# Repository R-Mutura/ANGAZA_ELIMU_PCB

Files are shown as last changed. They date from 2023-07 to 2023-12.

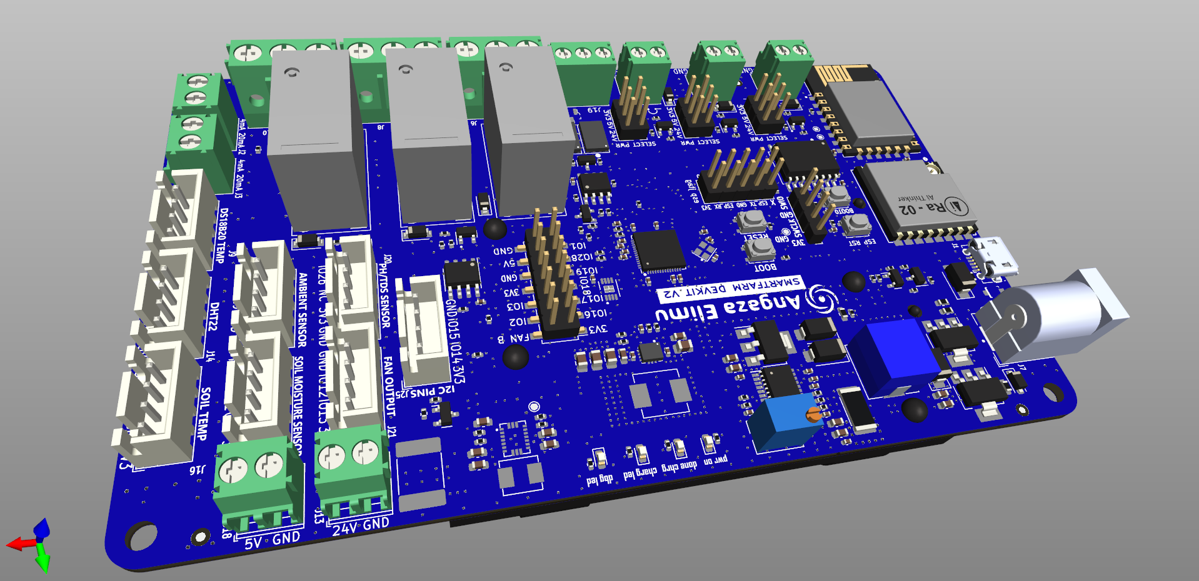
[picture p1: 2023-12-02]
images/RpiPico_Agriboard 4.png

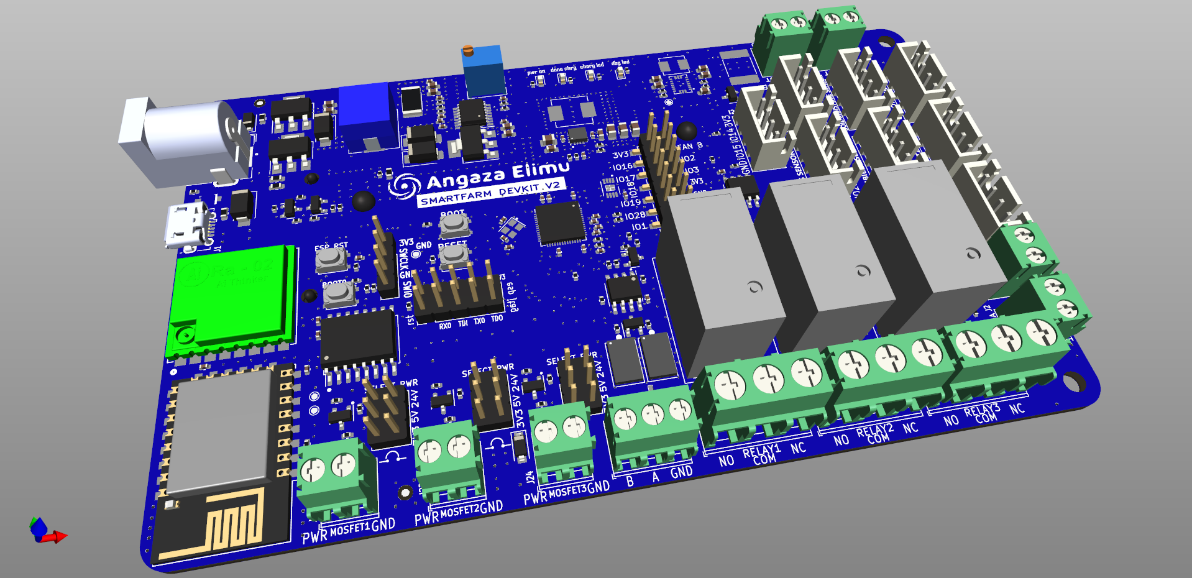
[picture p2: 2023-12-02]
images/RpiPico_Agriboard 3.png

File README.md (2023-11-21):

# ANGAZA_ELIMU_PCB

This repo contains the Hardware design and production files for the `Angaza Elimu Smart Farm` board.
 ###  Version 1.0.0 Solarless_Board 
 please refer to the attached release for all the production files.

## Description
The board main features of this Board include:
- RP2040TR7 - Rpi-Pico as the main MCU
- ESP12F - to prvide BLE and WiFi capabilties
- Lora Module RA-02 - with SMA connector  for extrnal antenna support - frequency 868mHz
- RS485 for communication with ground based sensor.
- Relay isolated outputs
- Mosfet Output with selectable power source - Lowside driver configuration
- 24V and 5V output - with overcurrent protection
- 0mA - 20mA  / 4mA - 20mA sensor input (eg Platinum temeprature sensor)
- and other communication interfaces

POWER FEATURES
- 24V  input
- Battery charger interface - MCP Lipo/LiIon charger with upto 1A output
- 5V boost convertor via TPS61022 - upto 3A output. Smart heat decipation incorporated into the PCB design
- 5V output Buck , 3V3 output Buck
- Low battery Threshold Trigger
- USB power input with ability for programming and troubleshooting.
## Items
In the repo you will find:
- 📁 3D_FILES - step files for mechanical linkage, design and reference
- 📁 ASSETS - Helpful matterial pertaining to the project - Datasheet, Design guides etc
- 📁 BOM - bill of materials
- 📁 Gerber - PCB manufacturing files
- 📁 Images -  Images for ease visaul inspection
- 📁 Placement_Files - Component assembly CSV files for use with Pick-n-Place machines
- 📁 SCH_PDF - PDF version of the schematic Design
- 📁 src - Contains all the Design files with relation to KiCad and the project. Should be accessed and modified by a skilled personel.
RpiPico_Agriboard 3
RpiPico_Agriboard 4

- # THANK YOU.

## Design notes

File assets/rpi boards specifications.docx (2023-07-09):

Introduction

Many factors affect the plant’s growth, such as light, water, carbon dioxide, temperature, moisture, soil salinity, pH, nutrients, pests, diseases, and so on. It’s important to learn the crop’s living environment to maximize plant growth.

Items To Monitor

Ambient Temperature and Humidity sensing (DHT22)

Extremely low or high temperatures stunt growth or cause foliage damage, or leaf drop. Relative humidity levels affect when and how plants open the stomata on the undersides of their leaves. That affects the plant’s breath.

Soil moisture and temperature ( FC-28 soil)

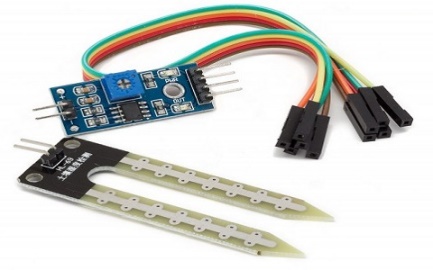
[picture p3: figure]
soil-moisture-sensor

- AM2315 Temperature - Humidity Sensor

https://www.amazon.com/AM2315-Digital-Signal-Temperature-Humidity/dp/B085X1QK4Z

# --DS18B20

Prototyping sensor

The soil temperature and moisture are key measure factors indicating soil temperature and water content. Soil temperature influences aeration, soil moisture content, and the availability of plant nutrients. And water content mainly indicates the need for irrigation.

Ambient Light(https://learn.sparkfun.com/tutorials/temt6000-ambient-light-sensor-hookup-guide/all) TEMT6000 Ambient Light Sensor Hookup Guide

The light sensor detects illuminance applied in agricultural planting. Many plants will do just fine with a wide variety of light levels while some plants require not too much or too little light. (For photosynthesis)

Soil Nutrient Level*

https://how2electronics.com/measure-soil-nutrient-using-arduino-soil-npk-sensor/

https://www.amazon.com/Taidacent-Detector-Agricultural-Phosphorus-Potassium/dp/B08MXXSP59

RS485 BOARD - https://www.robotistan.com/ttl-rs485-serial-converter-board-max485

- (search for protype of this)

Nutrient dosing to the plants can also be automated. You can achieve higher yields and better quality crops by providing plants with what they need when they need it.

When feeding plants with nutrients, the IoT system can accurately and precisely dose nutrient recipes allowing you to automate your entire fertilizer strategy from seedling to harvest.

PH Control* -- https://www.seeedstudio.com/Grove-PH-Sensor-Kit-E-201C-Blue-p-4577.html

PH Sensor Kit (E-201C-Blue ) – search for industrial

By using a PH sensor you can measure the soil PH. You can then set the target pH in your recipe up or down to hit your target pH and adjust for fluctuation in supply water.

Electrical Conductivity

Hardware Options

1. Lora

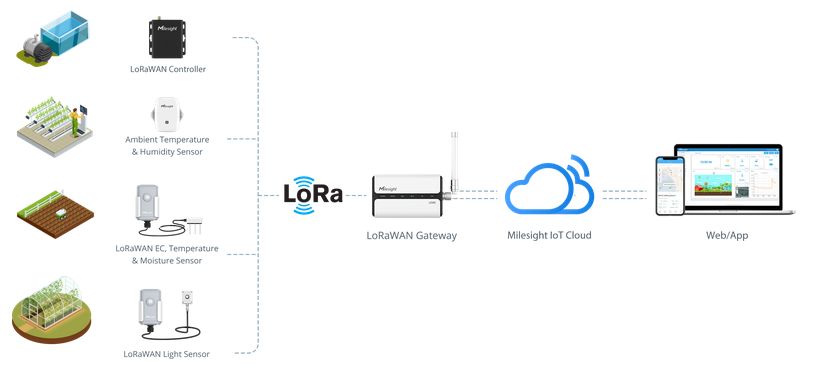
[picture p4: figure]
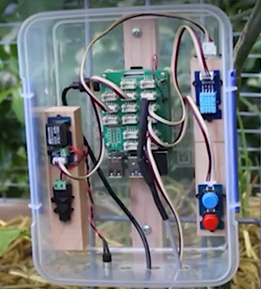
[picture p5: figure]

The gateway collects data from sensors which are in the field then sends them to the Angaza Elimu IoT cloud platform. Users can remotely monitor crop’s environmental conditions on the Angaza Elimu Cloud platform anytime anywhere.

Users can set up the threshold and receive an alert once the threshold is reached, then using the Controller (relay controller) to take action.

In addition, users can also set up combined triggers to automatically take actions. For example, an event can be scheduled to automatically turn on the pump for 20 minutes while the soil moisture level is less than 6%.

Components

- Ambient temperature and humidity sensor
- Soil temperature sensor
- Soil moisture sensor
- Ambient light sensor
- EC sensor
- Solar panel
- Charging circuit
- Relay controller
- Water pump
- UV light (for demonstrating light control in a indoor greenhouse)
- LoRa connectivity
- Lora gateway
- An IoT cloud platform

How it works

Microcontroller: Raspberry Pi Pico W

Programming Language: Python

Communication Protocol: LoRa

Data protocol: MQTT

Enclosure: An enclosure will be used to hold the sensors and microcontroller

Power options: Battery powered, direct connection for gateway, solar power

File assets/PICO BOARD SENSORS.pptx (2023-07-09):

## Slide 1

DHT22

MAIN BOAR WITH RPI PICO MCU AND CONNECTORS

DHT22 CONNECTOR

RS485

I2C1

DS18B20

DS18B20 CONNECTOR

TEMT-6000

TEMT-6000 CONNECTOR

SC228 LIGHT SENSOR

NPK NUTRIENT SENSOR

PH METER SENSOR

OTHER SENSORS

TDS

PH sensor

TDS CONNECTOR

UART

4-20 Ma Sensor

PH SENSOR CONNECTOR

I2C

Humidity and temp sensor

PROTOTYPE SENSORS

INDUSTRIAL SENSORS

CONNECTORS ON PCB

Humidity and temp sensor

Flow sensor

Level sensor

others sensor

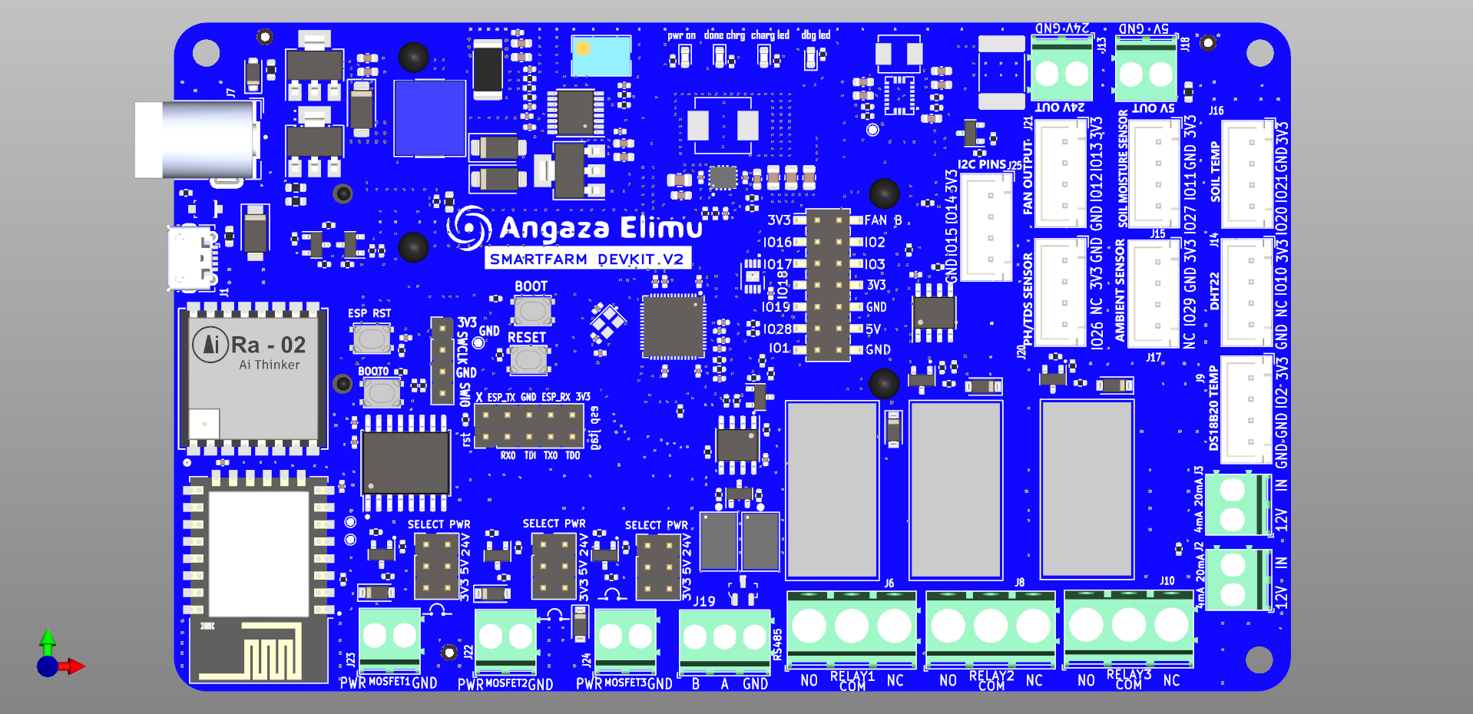
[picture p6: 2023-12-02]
images/RpiPico_Agriboard 1.png

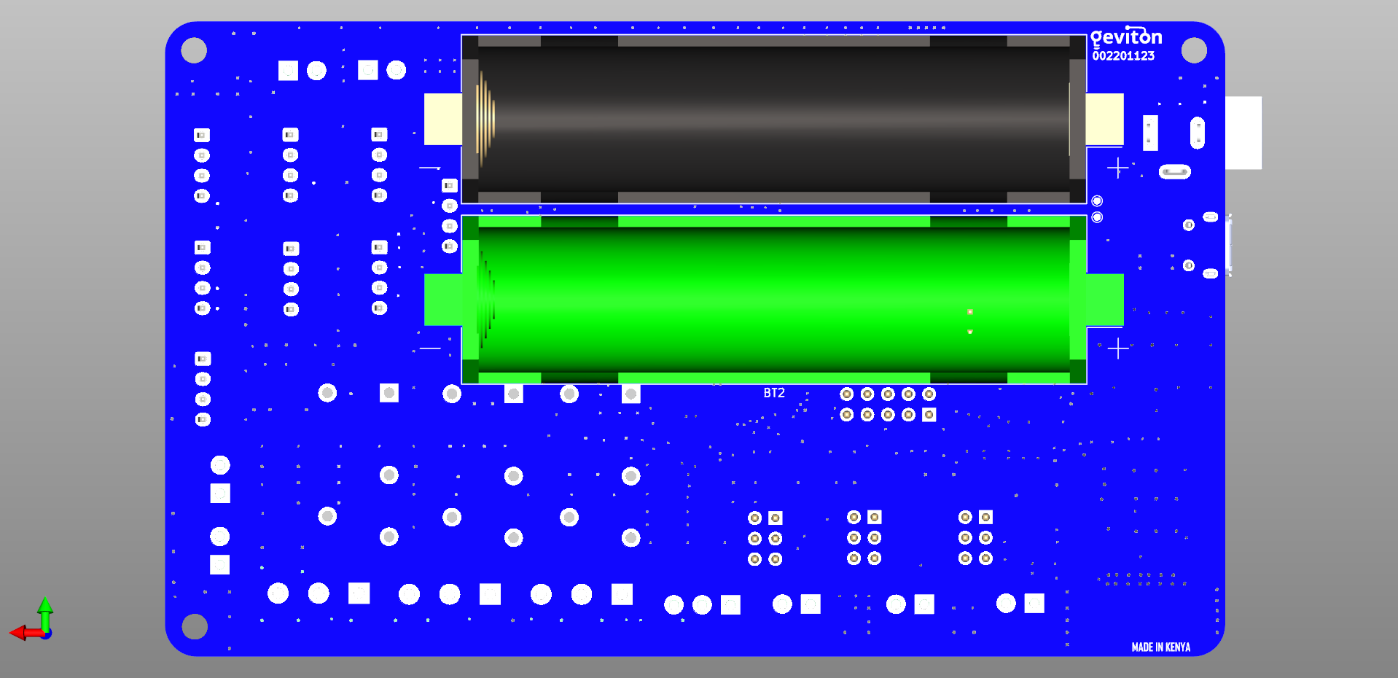
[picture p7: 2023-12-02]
images/RpiPico_Agriboard 2.png

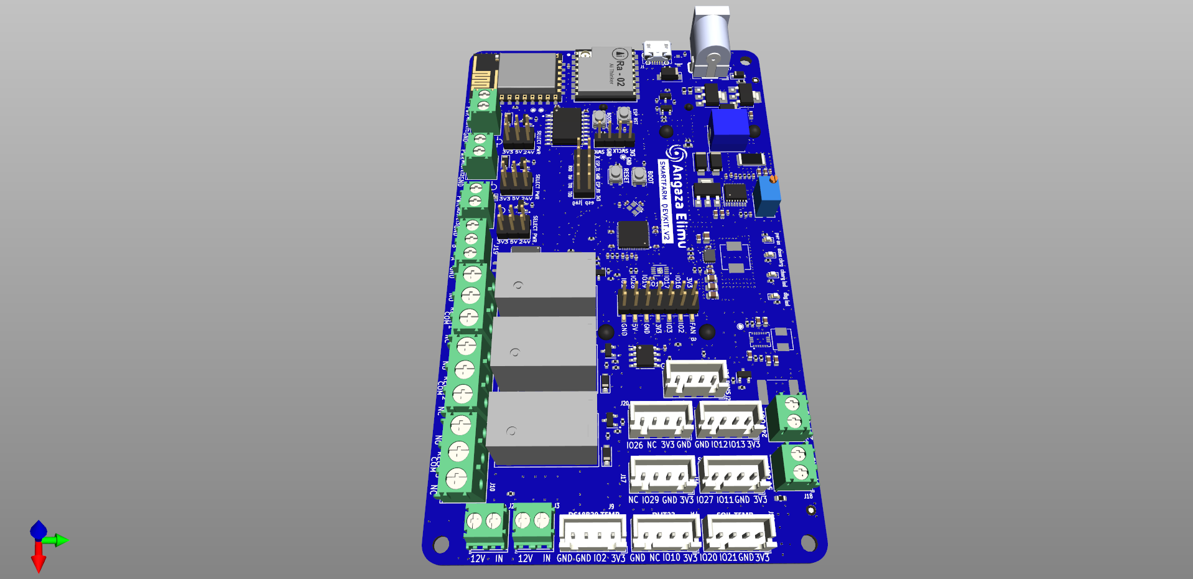
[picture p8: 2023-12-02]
images/RpiPico_Agriboard 5.png

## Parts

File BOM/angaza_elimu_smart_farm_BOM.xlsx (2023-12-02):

Reference(s) | Value | Footprint | MPN | Vendor | Qty
BT1, BT2 | 18650 BAT | Battery:BatteryHolder_Keystone_1042_1x18650 | BH-18650-A1AJ005 | LCSC | 2
C1, C4, C5 | 47u | Capacitor_SMD:C_0603_1608Metric | GRM188R60J476ME15D | LCSC | 3
C2, C3 | 100n | Capacitor_SMD:C_0603_1608Metric | 0603B104K500NT | LCSC | 2
C6, C9, C10, C11, C12, C13, C14, C16, C17, C18, C20, C21, C24, C27, C28, C32, C36, C38, C39, C44, C45, C78, C79 | 100n | Capacitor_SMD:C_0402_1005Metric | CL05B104KO5NNNC | LCSC | 23
C7, C8 | 22p | Capacitor_SMD:C_0402_1005Metric | CC0402JRNPO9BN220 | LCSC | 2
C19 | 2.2u | Capacitor_SMD:C_0402_1005Metric | CL05A225MQ5NSNC | LCSC | 1
C22 | 4.7u | Capacitor_SMD:C_0603_1608Metric | CL10A475KP8NNNC | LCSC | 1
C23, C25, C26, C29, C30 | 10u | Capacitor_SMD:C_0603_1608Metric | CL10A106MQ8NNNC | LCSC | 5
C31, C34 | 470p | Capacitor_SMD:C_0402_1005Metric | 0402B471K500NT | LCSC | 2
C33 | 220n | Capacitor_SMD:C_0402_1005Metric | 0402B224K160NT | LCSC | 1
C35, C41, C42, C43 | 22u>15V | Capacitor_SMD:C_0805_2012Metric | C2012X5R1V226MT000E | LCSC | 4
C37, C40 | 10u>15V | Capacitor_SMD:C_0603_1608Metric | GRM188R6YA106MA73D | LCSC | 2
C74, C75 | 100nF | Capacitor_SMD:C_0402_1005Metric | CC0402KRX7R7BB104 | LCSC | 2
D1 | LED | LED_SMD:LED_0603_1608Metric | SZYY0603B | LCSC | 1
D2 | BZT52Bxx | Diode_SMD:D_SOD-123F | BZT52H-B12,115 | LCSC | 1
D3, D8, D9, D10, D12, D13 | D_Schottky | Diode_SMD:D_SOD-123 | SS510A | LCSC | 6
D4 | SS34 | Diode_SMD:D_SMA | SS34 | LCSC | 1
D5, D6 | SS56 | Diode_SMD:D_SMA | SS56 | LCSC | 2
D7 | LED_GREEN | LED_SMD:LED_0603_1608Metric | SZYY0603G | LCSC | 1
D11 | D_Schottky | Diode_SMD:D_SMA | SS56 | LCSC | 1
D14 | PESD1CAN_215 | digikey-footprints:SOT-23-3 | PESD1CAN,215 | LCSC | 1
D15 | LED_RED | LED_SMD:LED_0603_1608Metric | SZYY0603R | LCSC | 1
D16 | LED_BLUE | LED_SMD:LED_0603_1608Metric | SZYY0603B | LCSC | 1
D17 | ESDONCAN1LT1G | Package_TO_SOT_SMD:SOT-23 | ESDONCAN1LT1G | LCSC | 1
J1 | USB_B_Micro | Connector_USB:USB_Micro-B_Molex-105017-0001 | 1050170001 | LCSC | 1
J2, J3, J13, J18, J22, J23, J24 | Screw_Terminal_01x02 | TerminalBlock_Phoenix:TerminalBlock_Phoenix_PT-1,5-2-3.5-H_1x02_P3.50mm_Horizontal | DB125-3.5-2P-GN-S | LCSC | 7
J4 | Conn_01x04 | Connector_PinHeader_2.54mm:PinHeader_1x04_P2.54mm_Vertical | B-2100S04P-A110 | LCSC | 1
J5 | Conn_02x07_Odd_Even | Connector_PinHeader_2.54mm:PinHeader_2x07_P2.54mm_Vertical_SMD | X6521WV-2x07H-C30D60 | LCSC | 1
J6, J8, J10 | Screw_Terminal_01x03 | TerminalBlock_Phoenix:TerminalBlock_Phoenix_PT-1,5-3-5.0-H_1x03_P5.00mm_Horizontal | PZ254-2-07-W-8.5 | LCSC | 3
J7 | Barrel_Jack_Switch | greencharge-footprints:BarrelJack_Wuerth_6941xx301002 | DC-005-20A | LCSC | 1
J9 | DS18B20 CONN | Connector_JST:JST_XH_B4B-XH-A_1x04_P2.50mm_Vertical | B4B-XH-A(LF)(SN) | LCSC | 1
J11, J12, J26 | Conn_02x03_Odd_Even | Connector_PinHeader_2.54mm:PinHeader_2x03_P2.54mm_Vertical | B-2100S06P-B110 | LCSC | 3
J14 | DHT22 CONN | Connector_JST:JST_XH_B4B-XH-A_1x04_P2.50mm_Vertical | B4B-XH-A(LF)(SN) | LCSC | 1
J15 | SOIL MOISTURE CONN | Connector_JST:JST_XH_B4B-XH-A_1x04_P2.50mm_Vertical | B4B-XH-A(LF)(SN) | LCSC | 1
J16 | SOIL TEMPERATURE CONN | Connector_JST:JST_XH_B4B-XH-A_1x04_P2.50mm_Vertical | B4B-XH-A(LF)(SN) | LCSC | 1
J17 | AMBIENT LIGHT CONN | Connector_JST:JST_XH_B4B-XH-A_1x04_P2.50mm_Vertical | B4B-XH-A(LF)(SN) | LCSC | 1
J19 | Screw_Terminal_01x03 | TerminalBlock_Phoenix:TerminalBlock_Phoenix_PT-1,5-3-3.5-H_1x03_P3.50mm_Horizontal |  | LCSC | 1
J20 | PH SENSOR | Connector_JST:JST_XH_B4B-XH-A_1x04_P2.50mm_Vertical | B4B-XH-A(LF)(SN) | LCSC | 1
J21 | fan connector | Connector_JST:JST_XH_B4B-XH-A_1x04_P2.50mm_Vertical | B4B-XH-A(LF)(SN) | LCSC | 1
J25 | Conn_01x04 | Connector_JST:JST_XH_B4B-XH-A_1x04_P2.50mm_Vertical | B4B-XH-A(LF)(SN) | LCSC | 1
J27 | Conn_02x05_Odd_Even | Connector_PinHeader_2.54mm:PinHeader_2x05_P2.54mm_Vertical | PZ254V-12-10P | LCSC | 1
K1, K2, K3 | G5Q-14 DC5 | Relay_THT:Relay_SPDT_Omron-G5Q-1 | G5Q-14 DC5 | LCSC | 3
L1 | 1u_inductor | greencharge-footprints:MDA4020-XXXX | MDA4020-1R0M | LCSC | 1
L2 | 15uH | greencharge-footprints:MDA1350-XXX | MDA1350-150M | LCSC | 1
L3 | 1.5u | Inductor_SMD:L_Vishay_IHLP-2525 | IHLP2525CZER1R5M01 | LCSC | 1
Q1, Q3 | IRLML5203TRPBF | Package_TO_SOT_SMD:SOT-23 | IRLML5203TRPBF | LCSC | 2
Q2, Q5, Q7, Q9, Q10, Q11 | AP3404 | Package_TO_SOT_SMD:SOT-23 | AP3404 | LCSC | 6
Q4 | IRLML0100TRPBF | Package_TO_SOT_SMD:SOT-23 | IRLML0100TRPBF | LCSC | 1
Q6, Q8 | BSP170P-VB | Package_TO_SOT_SMD:SOT-223-3_TabPin2 | BSP170P-VB | LCSC | 2
Q12 | BSP170P-VB | Package_TO_SOT_SMD:SOT-223-3_TabPin2 | BSP170P-VB | LCSC | 1
R1, R2, R9, R10, R15, R16, R18, R26, R27, R29, R34, R41, R63, R68, R71 | 10K | Resistor_SMD:R_0402_1005Metric | RC0402FR-0710KL | LCSC | 15
R3, R4, R6, R32, R45, R49, R53, R56, R59, R64, R70, R72, R73 | 100K | Resistor_SMD:R_0402_1005Metric | RC0402FR-07100KL | LCSC | 13
R5, R69 | 560K | Resistor_SMD:R_0402_1005Metric | RC0402FR-07560KL | LCSC | 2
R7, R17, R19, R28, R39, R40 | 1K | Resistor_SMD:R_0402_1005Metric | RC0402FR-071KL (https://www.lcsc.com/product-detail/span-style-background-color-ff0-Chip-span-span-style-background-color-ff0-Resistor-span-span-style-background-color-ff0-Su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) | LCSC | 6
R8 | 49.9R | Resistor_SMD:R_0603_1608Metric | RS-03K49R9FT | LCSC | 1
R11 | 200R | Resistor_SMD:R_0402_1005Metric | RC0402FR-07200RL | LCSC | 1
R12 | 1R | Resistor_SMD:R_0402_1005Metric | AECR0402F1R00T9 | LCSC | 1
R13, R14 | 27R | Resistor_SMD:R_0402_1005Metric | FRC0402F27R0TS | LCSC | 2
R20, R21, R35, R62, R67 | 4.7K | Resistor_SMD:R_0402_1005Metric | RC0402FR-074K7L | LCSC | 5
R22, R23 | 150R | Resistor_SMD:R_0402_1005Metric | RC0402FR-07150RL | LCSC | 2
R24, R31, R44, R48, R52, R55, R58, R61 | 100R | Resistor_SMD:R_0402_1005Metric | FRC0402F3241TS | LCSC | 8
R25 | 2.7K | Resistor_SMD:R_0402_1005Metric | RC0402FR-072K7L | LCSC | 1
R30 | 470R | Resistor_SMD:R_0402_1005Metric | 0402WGF4700TCE | LCSC | 1
R33, R46, R51, R54, R57, R60 | 2.5R | Resistor_SMD:R_0402_1005Metric | SCR0402F2R55 | LCSC | 6
R36 | 1K | Resistor_SMD:R_0603_1608Metric | RC0603FR-071KL | LCSC | 1
R37 | 10K | Resistor_SMD:R_0603_1608Metric | RC0603FR-0710KL | LCSC | 1
R38 | 100m R | Resistor_SMD:R_2512_6332Metric | FRL2512FR100TS | LCSC | 1
R42 | 97.6K | Resistor_SMD:R_0402_1005Metric | ARG02BTC9762 | LCSC | 1
R43, R74 | 120R | Resistor_SMD:R_0402_1005Metric | 0402WGF1200TCE | LCSC | 2
R47 | 6.34K | Resistor_SMD:R_0402_1005Metric | RTT026341FTH | LCSC | 1
R50 | 5.97K | Resistor_SMD:R_0402_1005Metric | RT0402BRD075K97L | LCSC | 1
R65, R66 | 10R | Resistor_SMD:R_0402_1005Metric | RC0402FR-0710RL | LCSC | 2
RV1 | 10K | Potentiometer_THT:Potentiometer_Bourns_3266Y_Vertical | 3266Y-1-103LF | LCSC | 1
SW1, SW2, SW3, SW4 | SW_Push | greencharge-footprints:SKRPACE010 | SKRPACE010 | LCSC | 4
TH1 | 10K | Resistor_SMD:R_0603_1608Metric | NCP18XH103F03RB | LCSC | 1
TH2, TH3 | BSMD0603L-150 | Fuse:Fuse_0603_1608Metric | BSMD0603L-150 | LCSC | 2
TH4 | TLC-LSMD100 | Fuse:Fuse_2920_7451Metric | TLC-LSMD100 | LCSC | 1
U1 | RT6154A/B | greencharge-footprints:RT6154A_B | RT6154AGQW | LCSC | 1
U2 | W25Q16JVUXIQ | Package_SON:WSON-8-1EP_3x2.5mm_P0.5mm_EP1.2x1.5mm_PullBack | W25Q128JVSIQ | LCSC | 1
U3 | RP2040TR7 | Package_DFN_QFN:QFN-56-1EP_7x7mm_P0.4mm_EP3.2x3.2mm | RP2040TR7 | LCSC | 1
U4 | ESP-12F | RF_Module:ESP-12E | ESP-12F(ESP8266MOD) | LCSC | 1
U5 | CN3722 | Package_SO:HTSSOP-16-1EP_4.4x5mm_P0.65mm_EP3.4x5mm | CN3722 | LCSC | 1
U6 | Ai-Thinker-Ra-02 | RF_Module:Ai-Thinker-Ra-01-LoRa | Ra-02 | LCSC | 1
U7 | PCF8574A | Package_SO:SOIC-16W_7.5x10.3mm_P1.27mm | PCF8574AT | LCSC | 1
U8 | TP8485E-SR | Package_SO:SOIC-8_3.9x4.9mm_P1.27mm | TP8485E-SR | LCSC | 1
U9 | TPS63070RNMT | greencharge-footprints:VREG_TPS63070RNMR | TPS63070RNMT | Digikey | 1
U10, U11 | TBU-CA065-200-WH | MACHADA_footprints:TBU-CA065-200-WH | TBU-CA065-200-WH | LCSC | 2
U12 | PCA9536D | Package_SO:SOIC-8_3.9x4.9mm_P1.27mm | PCA9536D | LCSC | 1
Y1 | 12MHz | Crystal:Crystal_SMD_2520-4Pin_2.5x2.0mm | SX2B12.000F1210F30 | LCSC | 1
Z1 | MMSZ5231B-7-F | digikey-footprints:SOD-123 | MMSZ5231B-7-F | LCSC | 1

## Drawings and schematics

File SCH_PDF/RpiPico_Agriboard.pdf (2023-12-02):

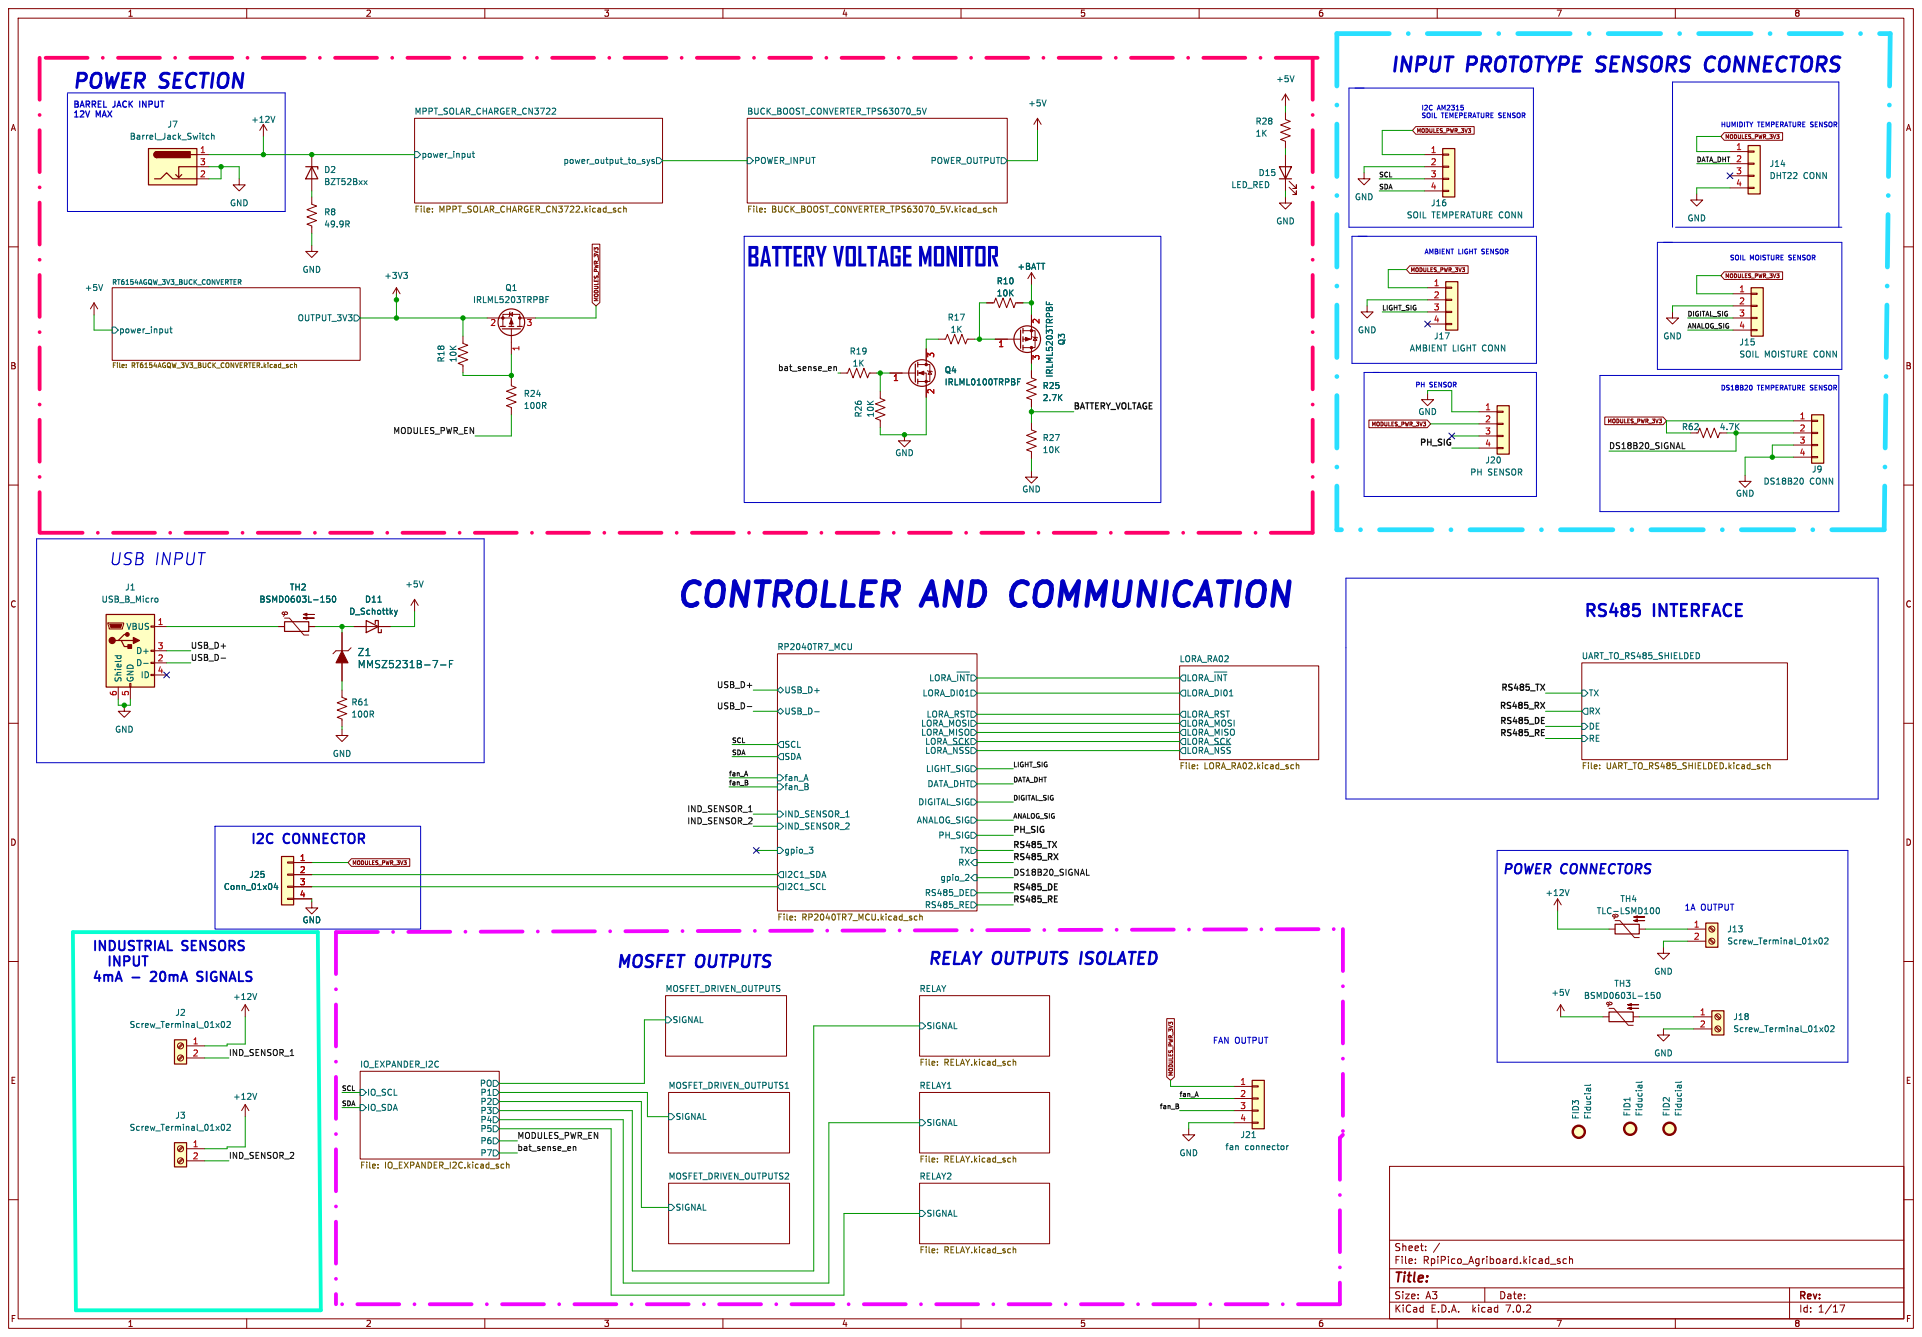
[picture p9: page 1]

FAN OUTPUT BATTERY VOLTAGE MONITOR

INPUT PROTOTYPE SENSORS CONNECTORS

I2C AM2315 SOIL TEMEPERATURE SENSOR MOSFET OUTPUTS
HUMIDITY TEMPERATURE SENSOR CONTROLLER AND COMMUNICATION

AMBIENT LIGHT SENSOR USB INPUT

SOIL MOISTURE SENSOR RS485 INTERFACE

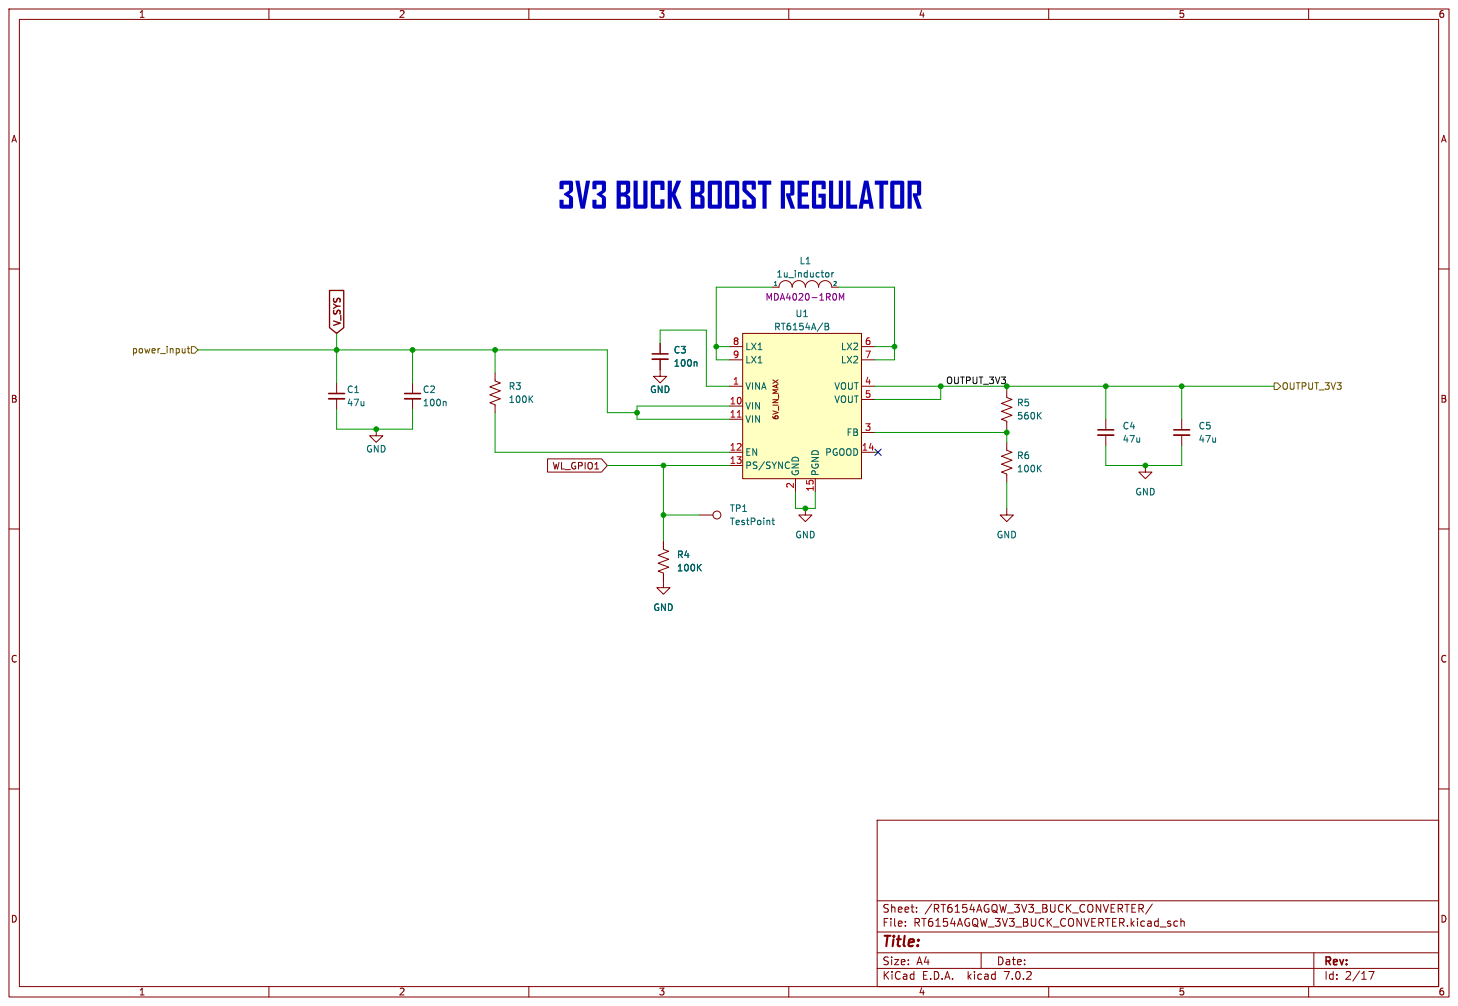
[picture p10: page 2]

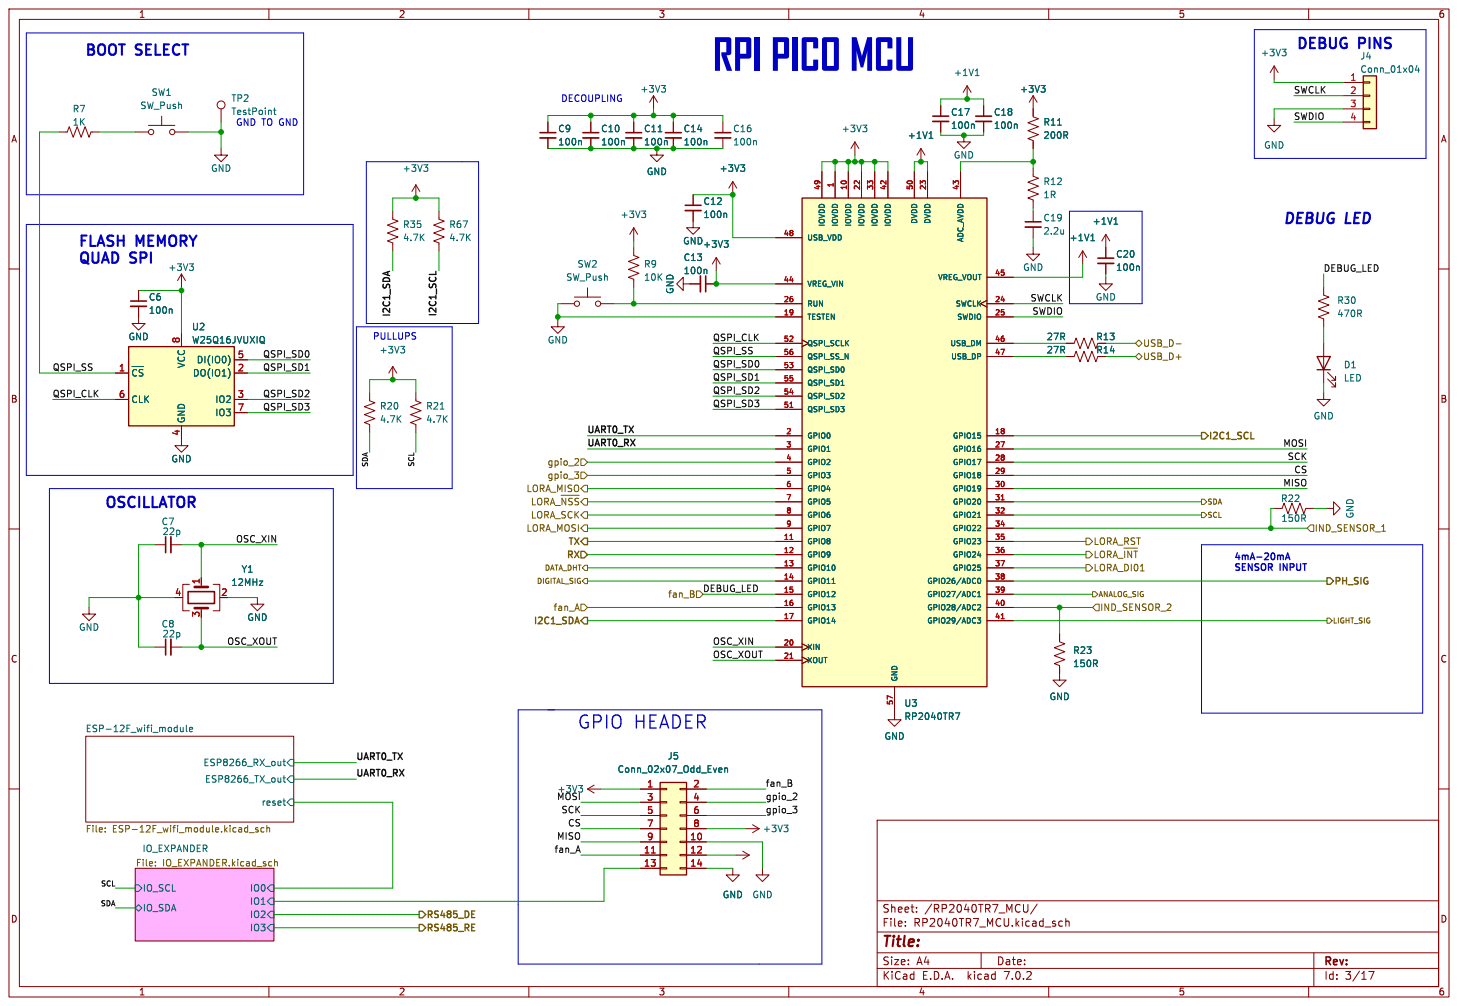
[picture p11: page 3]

1 IOVDD 10 GPIO8 11 GPIO9 12 GPIO10 13 GPIO11 14 GPIO12 15 GPIO13 16 GPIO14 17 GPIO15 18 TESTEN 19 GPIO0 2 XIN 20 XOUT 21 IOVDD 22 DVDD 23 SWCLK 24 SWDIO 25 RUN 26 GPIO16 27 GPIO17 28 GPIO18 29 GPIO1 3 GPIO19 30 GPIO20 31 GPIO21 32 IOVDD 33 GPIO22 34 GPIO23 35 GPIO24 36 GPIO25 37 GPIO26/ADC0 38 GPIO27/ADC1 39 GPIO2 4 GPIO28/ADC2 40 GPIO29/ADC3 41 IOVDD 42 ADC_AVDD 43 VREG_VIN 44 VREG_VOUT 45 USB_DM 46 USB_DP 47 USB_VDD 48 IOVDD 49 GPIO3 5 DVDD 50 QSPI_SD3 51 QSPI_SCLK 52 QSPI_SD0 53 QSPI_SD2 54 QSPI_SD1 55 QSPI_SS_N 56 GND 57 GPIO4 6 GPIO5 7 GPIO6 8 GPIO7 9 GND GND GND

1 IOVDD 10 GPIO8 11 GPIO9 12 GPIO10 13 GPIO11 14 GPIO12 15 GPIO13 16 GPIO14 17 GPIO15 18 TESTEN 19 GPIO0 2 XIN 20 XOUT 21 IOVDD 22 DVDD 23 SWCLK 24 SWDIO 25 RUN 26 GPIO16 27 GPIO17 28 GPIO18 29 GPIO1 3 GPIO19 30 GPIO20 31 GPIO21 32 IOVDD 33 GPIO22 34 GPIO23 35 GPIO24 36 GPIO25 37 GPIO26/ADC0 38 GPIO27/ADC1 39 GPIO2 4 GPIO28/ADC2 40 GPIO29/ADC3 41 IOVDD 42 ADC_AVDD 43 VREG_VIN 44 VREG_VOUT 45 USB_DM 46 USB_DP 47 USB_VDD 48 IOVDD 49 GPIO3 5 DVDD 50 QSPI_SD3 51 QSPI_SCLK 52 QSPI_SD0 53 QSPI_SD2 54 QSPI_SD1 55 QSPI_SS_N 56 GND 57 GPIO4 6 GPIO5 7 GPIO6 8 GPIO7 9 U3 RP2040TR7

SENSOR INPUT PULLUPS FLASH MEMORY

File: IO_EXPANDER.kicad_sch ESP8266_TX_out ESP8266_RX_out reset ESP-12F_wifi_module File: ESP-12F_wifi_module.kicad_sch

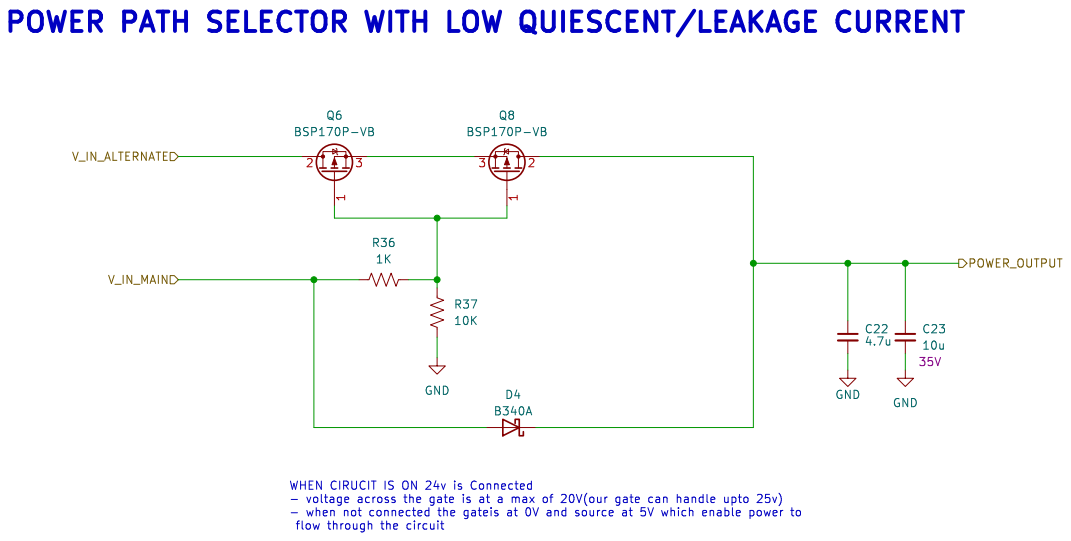
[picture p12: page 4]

- voltage across the gate is at a max of 20V(our gate can handle upto 25v)

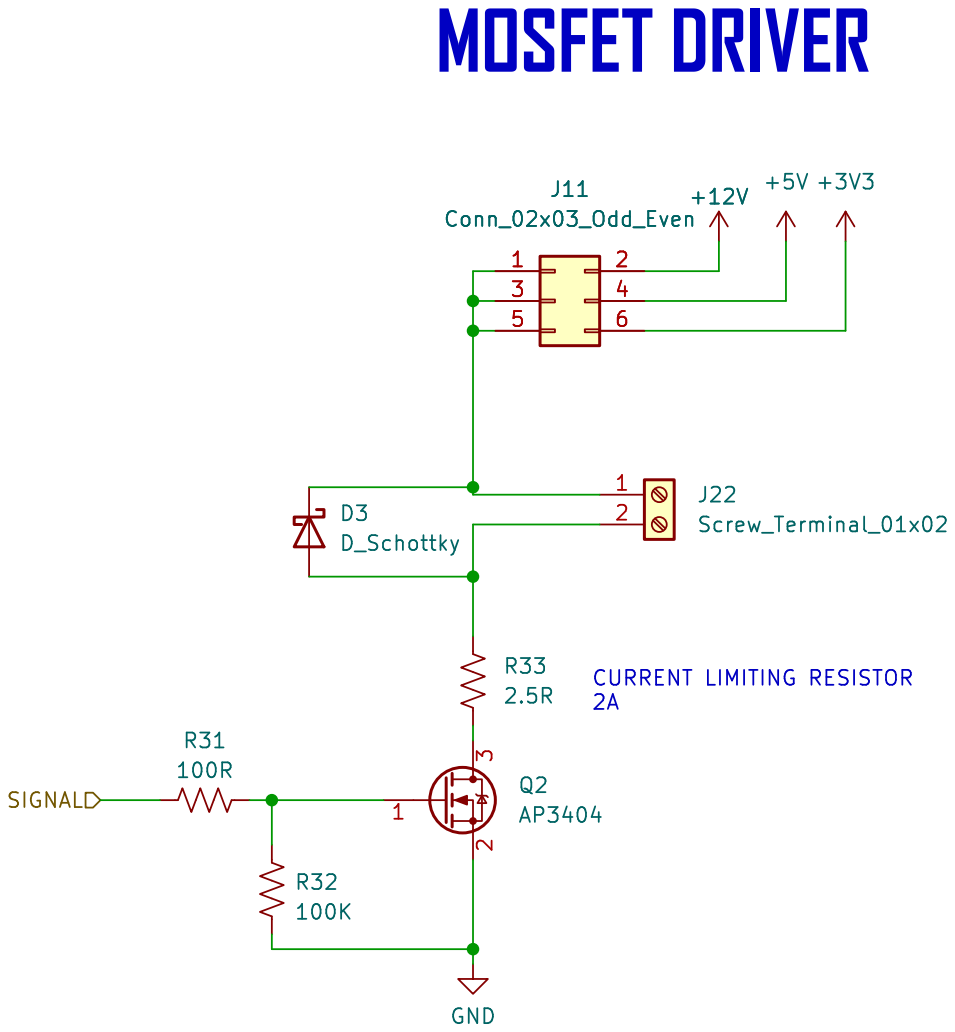
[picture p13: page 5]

3 3 | 4 4
5 5 | 6 6

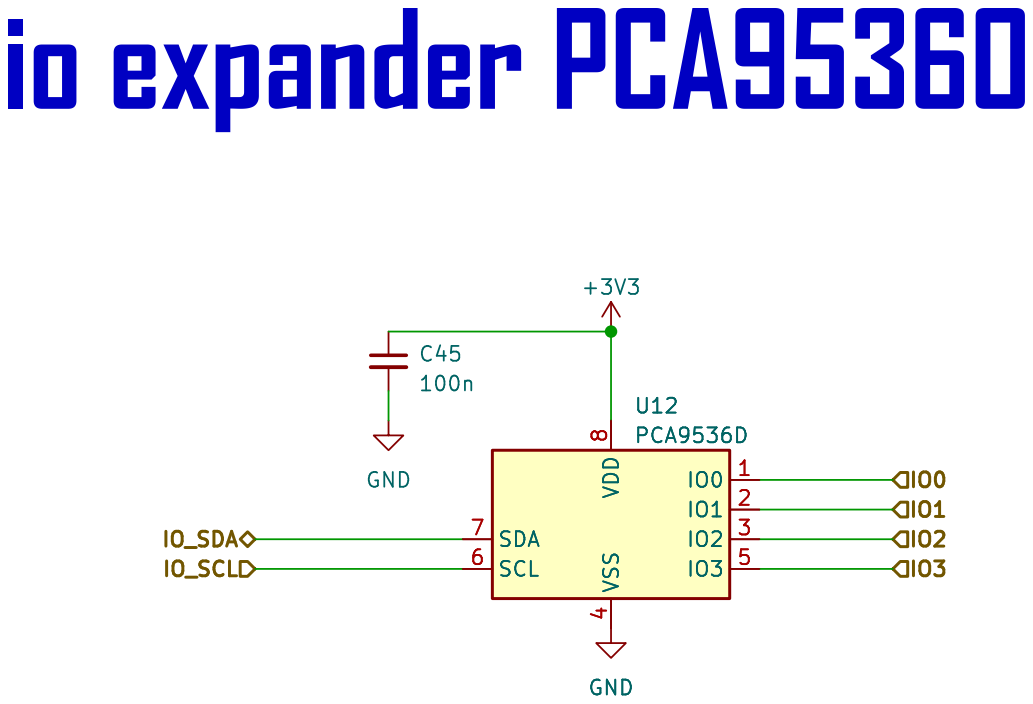
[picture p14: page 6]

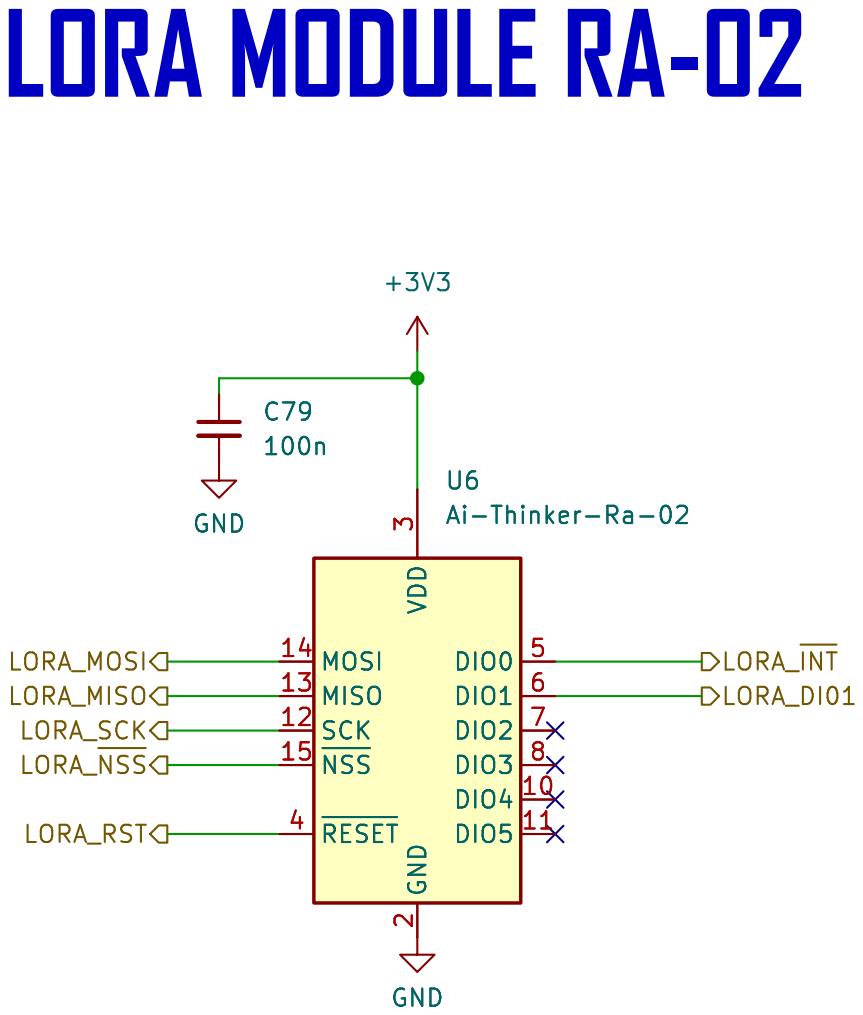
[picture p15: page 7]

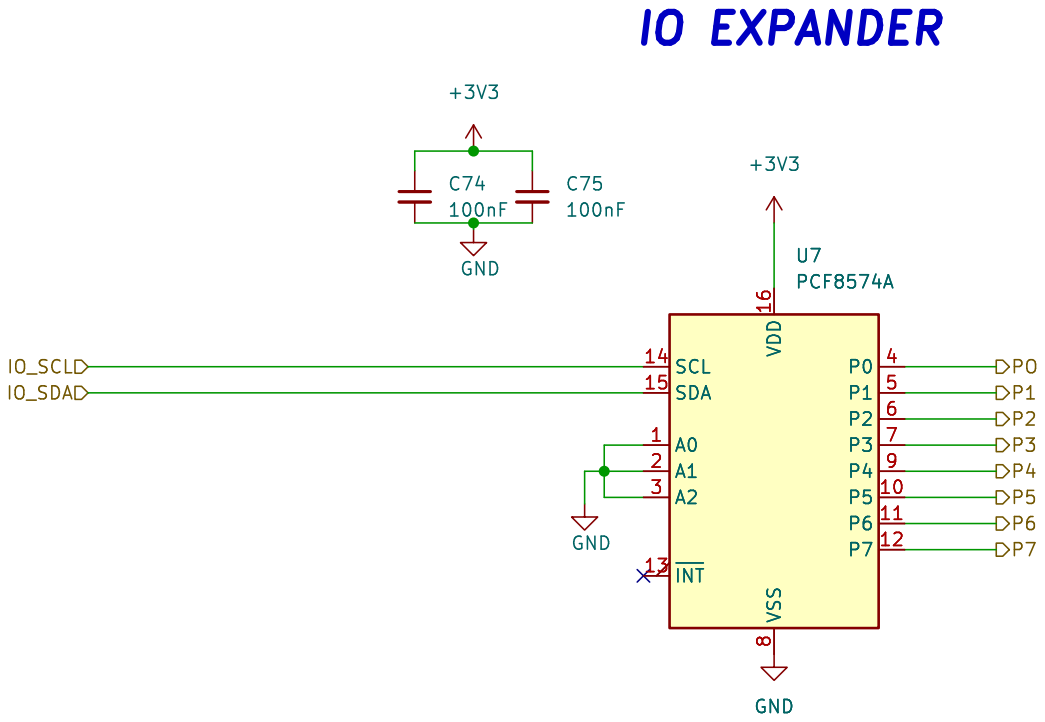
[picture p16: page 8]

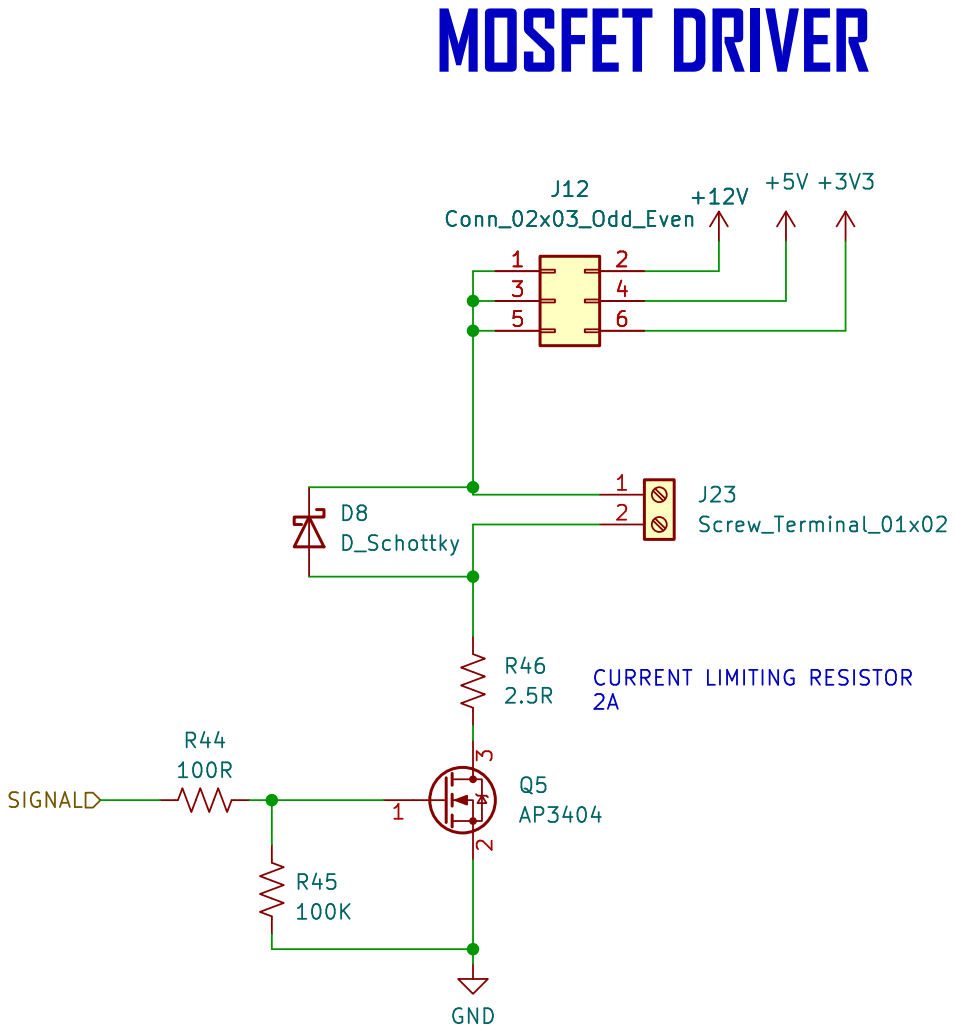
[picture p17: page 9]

3 3 | 4 4
5 5 | 6 6

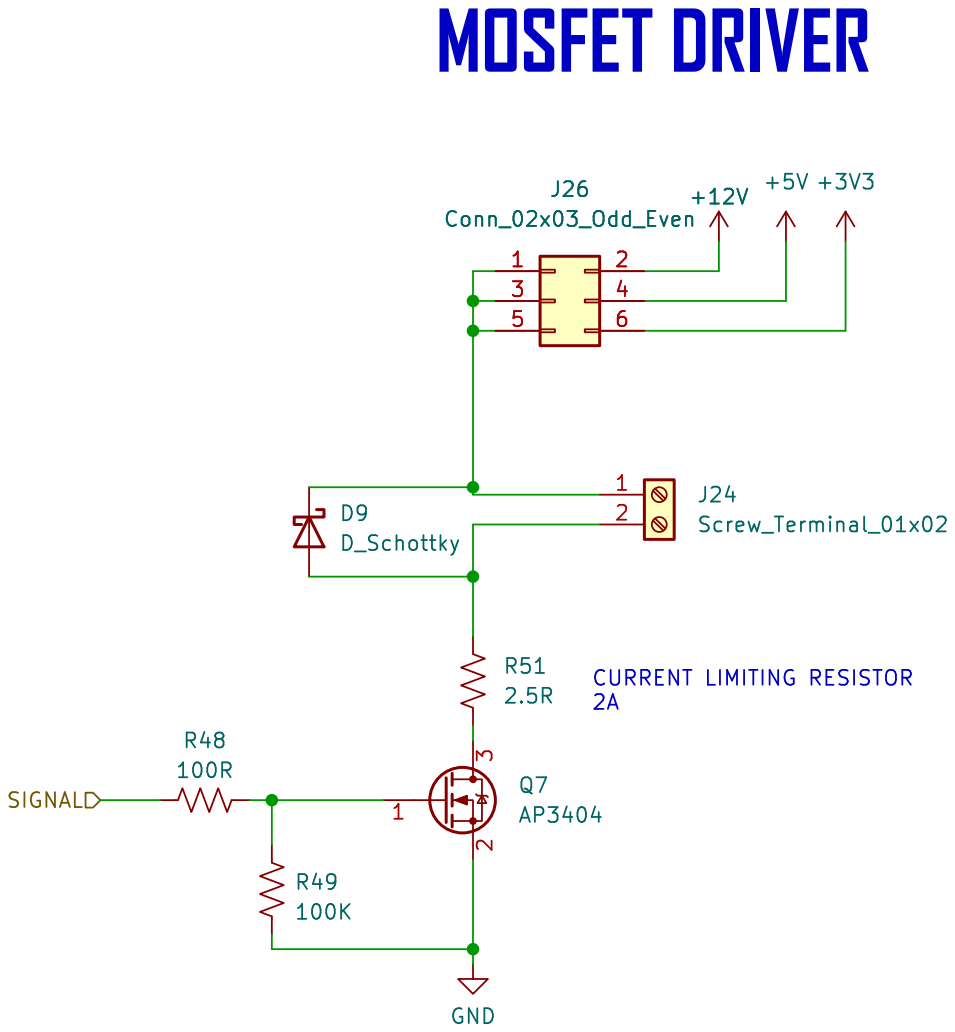
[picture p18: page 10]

3 3 | 4 4
5 5 | 6 6

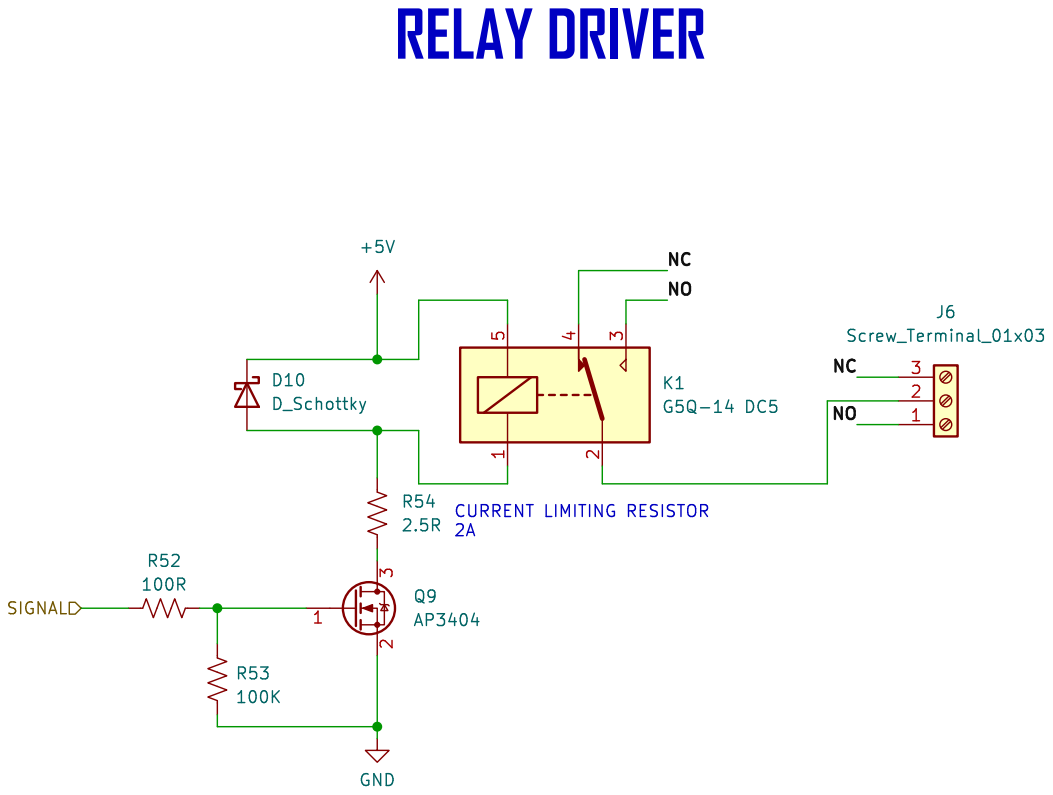
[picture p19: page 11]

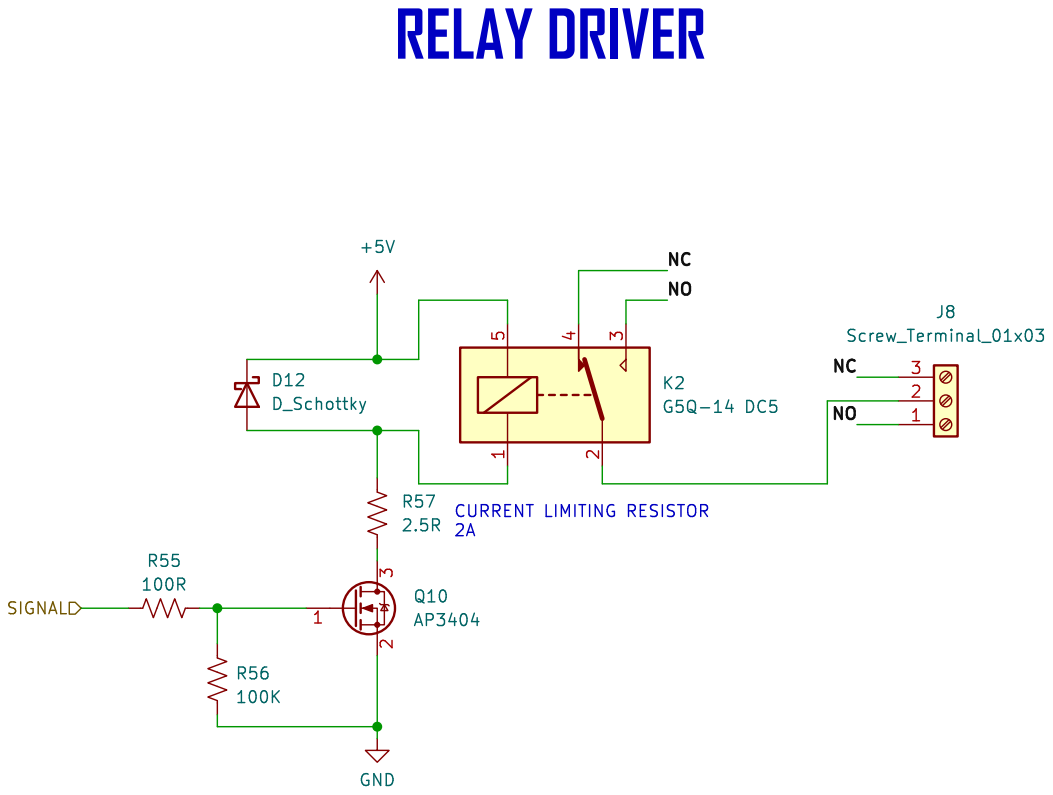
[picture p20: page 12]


3 ~{CHRG} 4 ~{DONE} 5 TEMP 6 MPPT 7 COM1 8 COM2 9 D5 B340A

3 ~{CHRG} 4 ~{DONE} 5 TEMP 6 MPPT 7 COM1 8 COM2 9 U5 CN3722 C26

þÿVBATÿ þÿ2.416×(1ÿ þÿR7ÿ þÿR6)ÿIB× R7 OPTIMIZED FOR 17.0V MAX POWER POINT





Id: 16/17 Title: File: UART_TO_RS485_SHIELDED.kicad_sch Sheet: /UART_TO_RS485_SHIELDED/





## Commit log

2023-07-09 completed anagaza elimu project
    [5V_2A_BUCK_BOOST.kicad_sch, ESP-12F_wifi_module.kicad_sch, IO_EXPANDER_I2C.kicad_sch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]
2023-07-29 updated gerber files
    [RpiPico_Agriboard-B_Cu.gbr, RpiPico_Agriboard-B_Mask.gbr, RpiPico_Agriboard-B_Paste.gbr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]
2023-11-20 original version completed
    [RpiPico_Agriboard.xlsx]
2023-11-20 new release branch added
    [RpiPico_Agriboard.kicad_sch]
2023-11-21 final release updates
    [RP2040TR7_MCU.kicad_sch]
2023-11-25 schematic updates completed
    [BUCK_BOOST_CONVERTER_TPS63070_5V.kicad_sch, ESP-12F_wifi_module.kicad_sch, LORA_RA02.kicad_sch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]
2023-11-25 Revert "schematic updates completed"
    This reverts commit 0124993096667d53f20fd59dec80d3f5a1efcd43.
    [BUCK_BOOST_CONVERTER_TPS63070_5V.kicad_sch, ESP-12F_wifi_module.kicad_sch, LORA_RA02.kicad_sch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]
2023-11-25 latest commit for the new solarfied version
    [BUCK_BOOST_CONVERTER_TPS63070_5V.kicad_sch, ESP-12F_wifi_module.kicad_sch, LORA_RA02.kicad_sch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]
2023-11-26 power module supply line increase and reupdates on schematic
    [ESP-12F_wifi_module.kicad_sch, LORA_RA02.kicad_sch, RELAY.kicad_sch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]
2023-11-26 updates on schematic-esp_rst, io expander, layout
    [BUCK_BOOST_CONVERTER_TPS63070_5V.kicad_sch, IO_EXPANDER.kicad_sch, MPPT_SOLAR_CHARGER_CN3722.kicad_sch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]
2023-11-27 layut updates, 3v3 sensor pwr updates
    [ESP-12F_wifi_module.kicad_sch, MOSFET_DRIVEN_OUTPUTS.kicad_sch, RpiPico_Agriboard.kicad_pcb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]
2023-11-28 updates on the through hole components
    [RP2040TR7_MCU.kicad_sch, RpiPico_Agriboard.kicad_pcb]
2023-11-28 rs485 updates and layout updates
    [RP2040TR7_MCU.kicad_sch, RpiPico_Agriboard.kicad_pcb, RpiPico_Agriboard.kicad_sch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]
2023-12-02 complete board update and routing
    [ESP-12F_wifi_module.kicad_sch, LORA_RA02.kicad_sch, MOSFET_DRIVEN_OUTPUTS.kicad_sch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]
